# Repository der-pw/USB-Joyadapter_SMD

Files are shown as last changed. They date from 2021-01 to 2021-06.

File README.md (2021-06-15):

# USB-Joyadapter_SMD  
ATtiny basierter USB adapter für classic DB9 joysticks.

Die Ursprungsidee kommt aus dem forum64.de.  
https://www.forum64.de/index.php?thread/43055-usb-joystickadapter-neue-firmware-weiterentwicklung/

Die Software ist frei verfügbar und wird u.a. in dem [Thread](https://www.forum64.de/index.php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) zum Download angeboten, alle anderen Quellen, zumindest die, die ich gefunden habe, laufen ins Leere.
Daher stelle ich die Daten, der Vollständigkeit halber in dem Ordner [USB-Joystickadapter_THT](https://github.com/der-pw/USB-Joyadapter_SMD/tree/main/USB-Joystickadapter_THT) mit zur Verfügung. Darin enthalten sind sowohl die Software, zwei kompillierte Versionen, einmal für ATtiny2313 und ATtiny4313 und zusätzlich auch die Boarddaten der "alten" THT-Version.  
Ich bin aber nicht der Author!

Ich wollte eine SMD Version, möglichst kompakt aber noch gut zum Handlöten, haben.
Das Platinenlayout liegt als [KiCad-Projekt](https://github.com/der-pw/USB-Joyadapter_SMD/tree/main/kicad) vor. Exportierte Gerberdaten für Fertiger (bspw. [JLCPCB](https://jlcpcb.com/)) kann man ebenfalls [hier herunterladen](https://github.com/der-pw/USB-Joyadapter_SMD/raw/main/Joyadapter_SMD_gerber.zip).

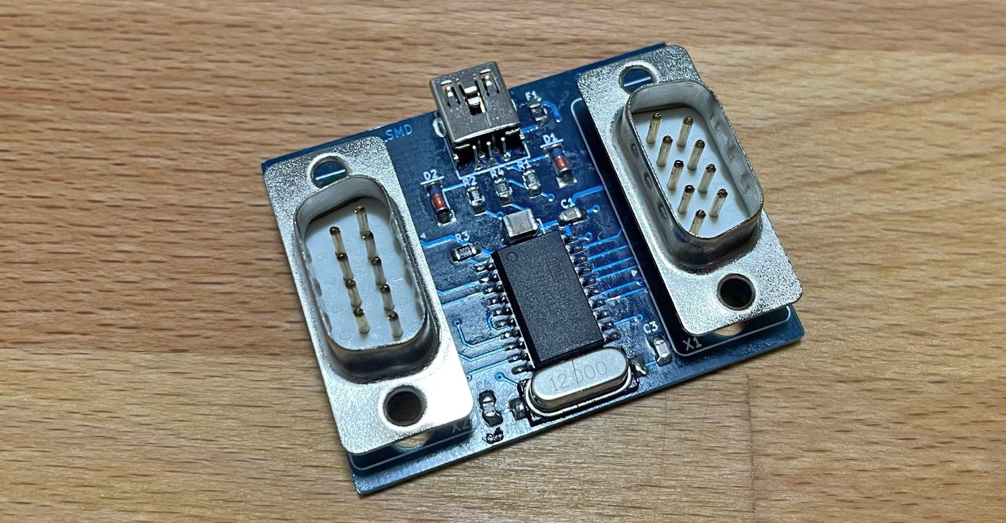
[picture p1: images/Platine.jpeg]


### Programmierung
Ich habe das Hexfile mittels [AVRDUDESS](https://github.com/zkemble/AVRDUDESS) und einem ISP-Programmer auf den ATtiny geschrieben.
Die ISP-Schnittstelle wurde aus Platzgründen als SMD-Pads ausgeführt.
Eine Möglichkeit, man lötet Verbindungskabel zum Programmer an, ober man baut mit einer Buchsenleiste 6x1 RM2,54, 6 Pogo-Pins (P50-B1) und dem [Adapter](https://github.com/der-pw/USB-Joyadapter_SMD/blob/main/3D%20print/Pogo-Adapter.stl) eine Programmierklemme.
Da man das Teil prinzipiell nur einmal flashed und die Software ist m.E. ausentwickelt, kann man wohl eher kurz ein paar Kabel anlöten.

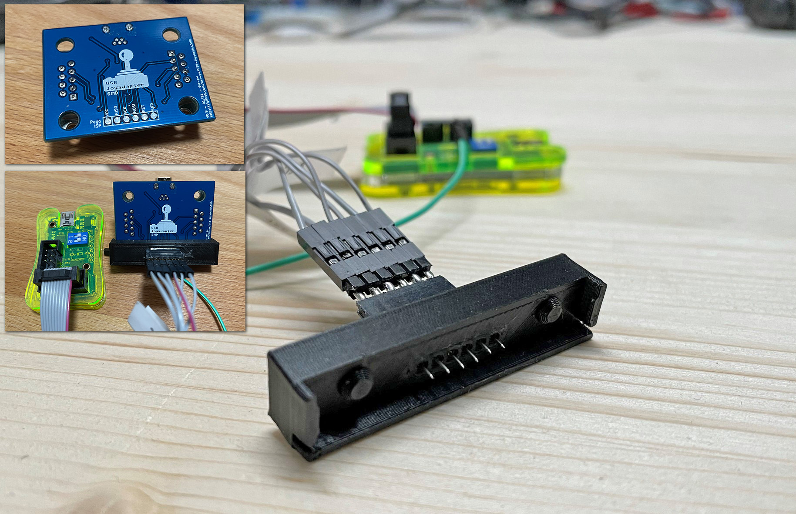
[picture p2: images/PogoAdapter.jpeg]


Die Fuses habe ich folgendermaßen gesetzt.  
**Low:** *0xCF*  
**High:** *0xDB*  
**Ext:** *0xFF*  
Fusecalc: https://www.engbedded.com/fusecalc/

### Gehäuse
Es gibt auch ein Gehäuse in der Variante mit den hochstehenden DB9-Buchsen.  
Zum Festschrauben beider Gehäusehälften wurden 2x12mm Linsenkopfschrauben verwendet.

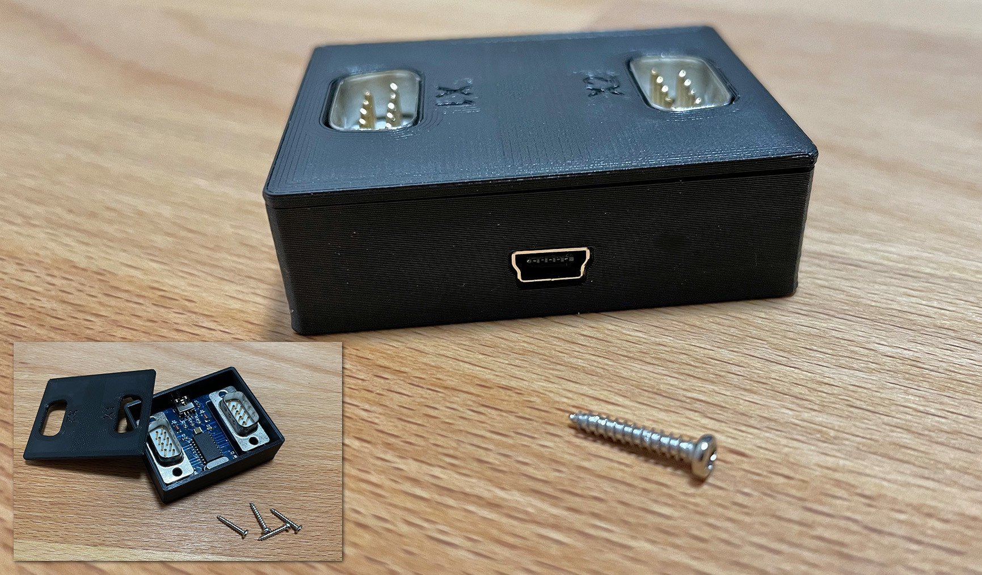
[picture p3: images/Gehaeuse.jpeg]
Gehäuse


Alternativ könnte man auch 90° gewinkelte DB9-Buchsen verwenden. Dann gucken die Kabel rechts und links aus dem Gehäuse heraus.
Ich wollte es erst einmal recht kompakt haben.
Vielleicht ergibt sich nochmal die Gelegenheit für ein Gehäuse mit 90° Buchsen.

### Teileliste:
https://www.reichelt.de/my/1803950  
Einige Teile sind (Stand 06.21) schwer zu bekommen.  

Ein großer **Dank** geht an das [forum64.de](https://www.forum64.de/) und seine hilfsbereiten Mitglieder. :thumbsup:

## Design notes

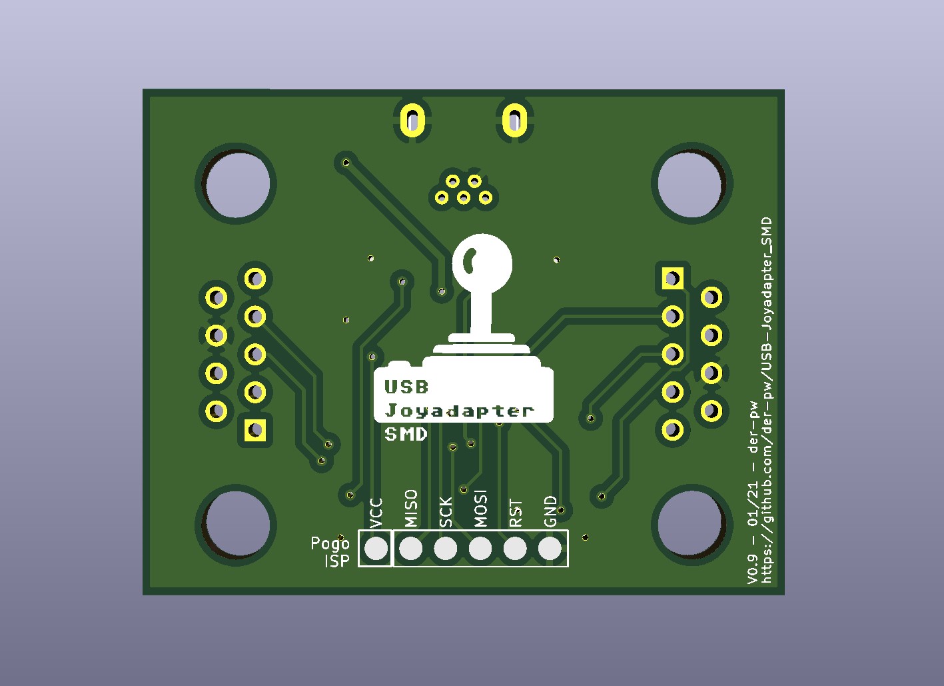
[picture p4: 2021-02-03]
images/3D_bottom_side.jpg

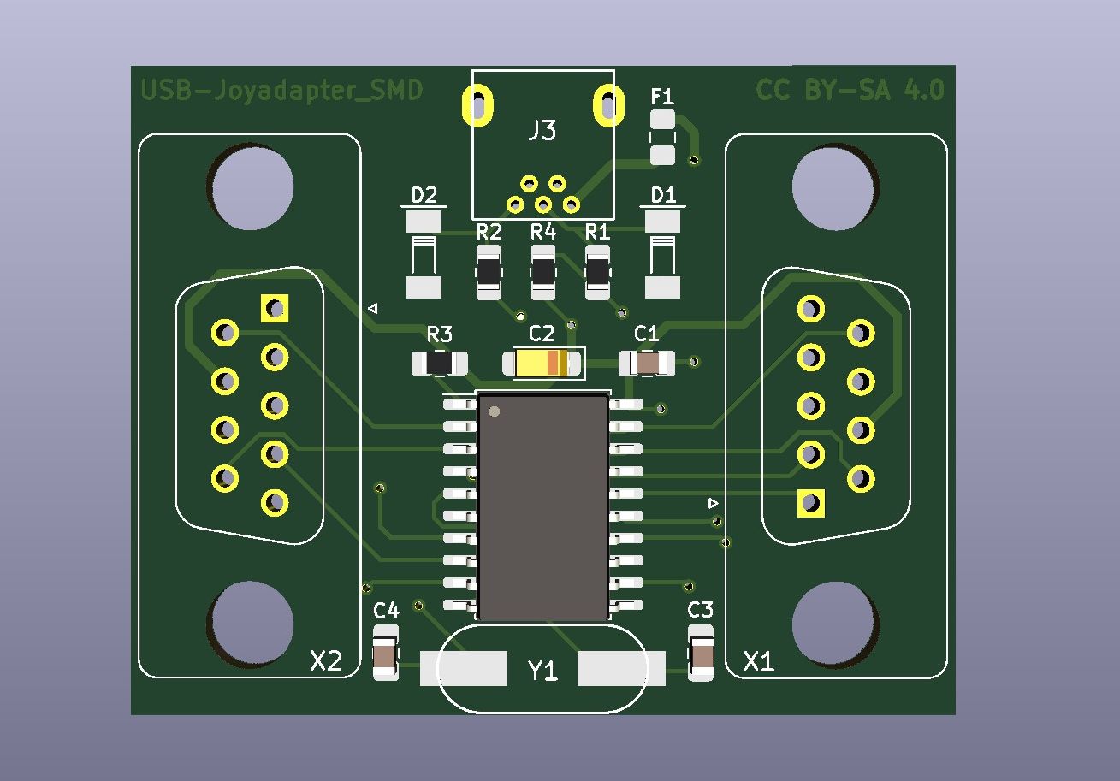
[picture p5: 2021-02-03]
images/3D_top_side.jpg

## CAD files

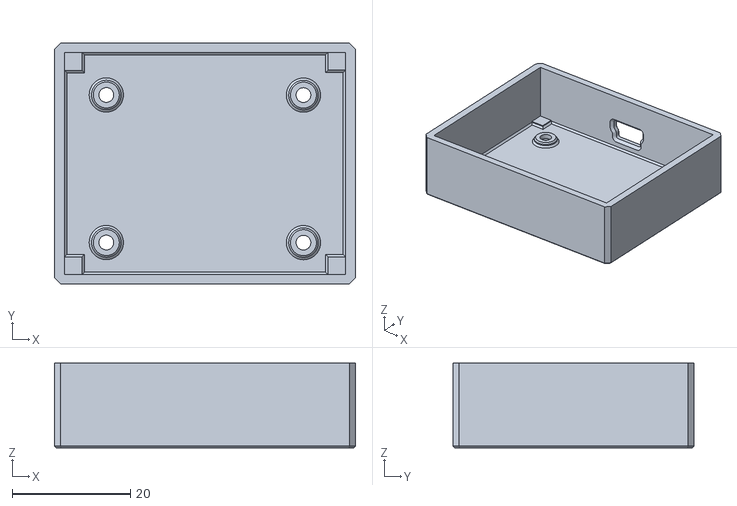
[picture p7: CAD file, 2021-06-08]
3D print/Case_bottom.stl
51.0 x 40.8 x 14.4

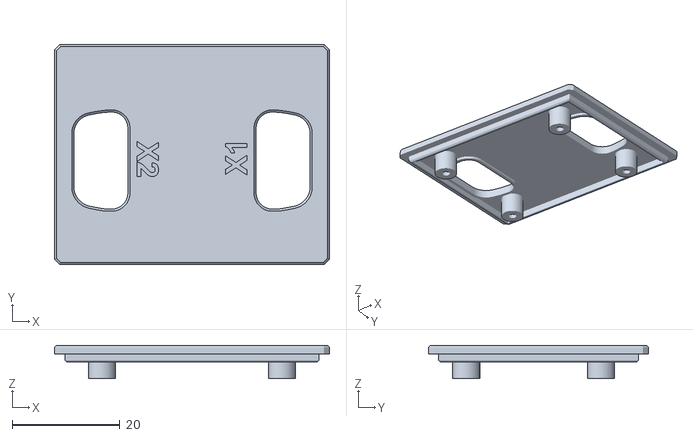
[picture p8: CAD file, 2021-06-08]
3D print/Case_top.stl
51.0 x 40.8 x 6.20

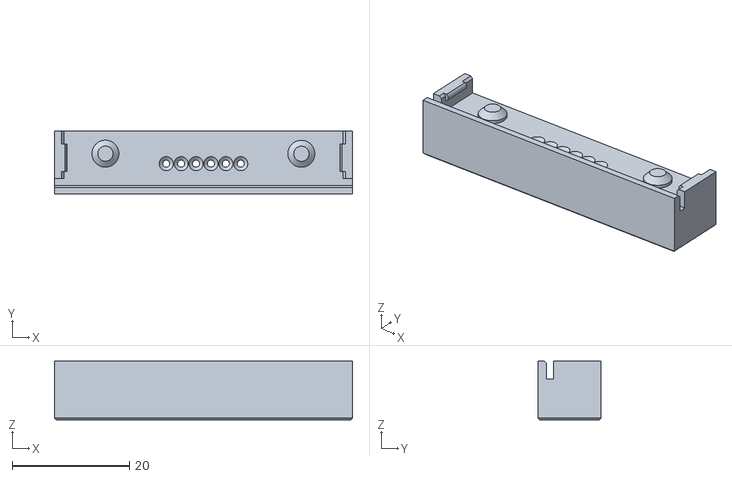
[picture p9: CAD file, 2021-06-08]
3D print/Pogo-Adapter.stl
50.8 x 10.8 x 10.0

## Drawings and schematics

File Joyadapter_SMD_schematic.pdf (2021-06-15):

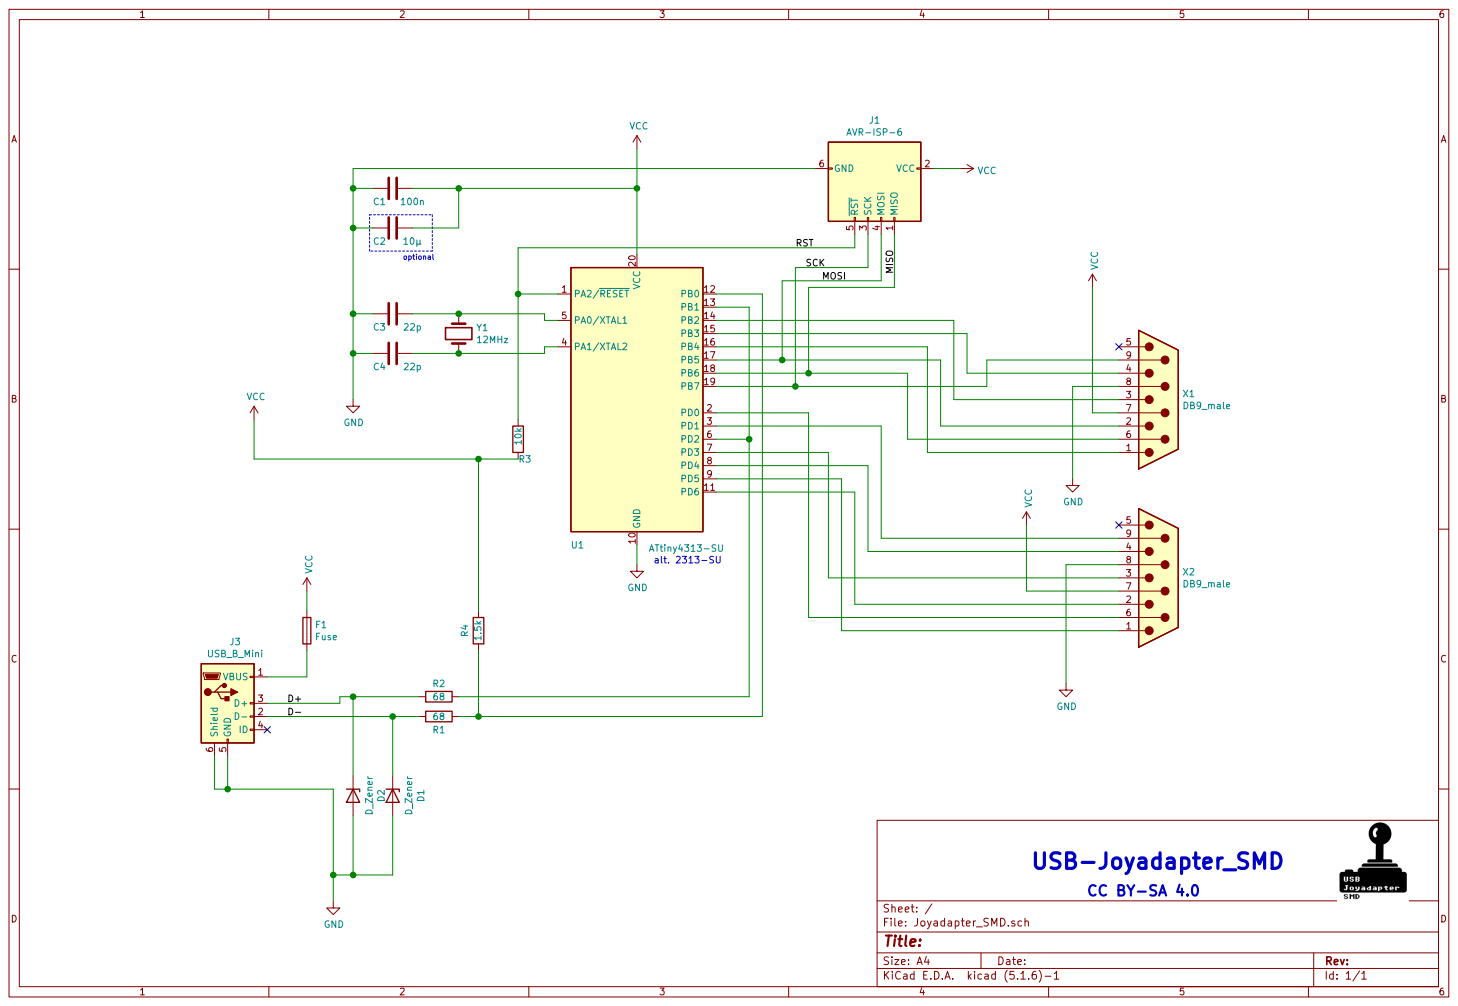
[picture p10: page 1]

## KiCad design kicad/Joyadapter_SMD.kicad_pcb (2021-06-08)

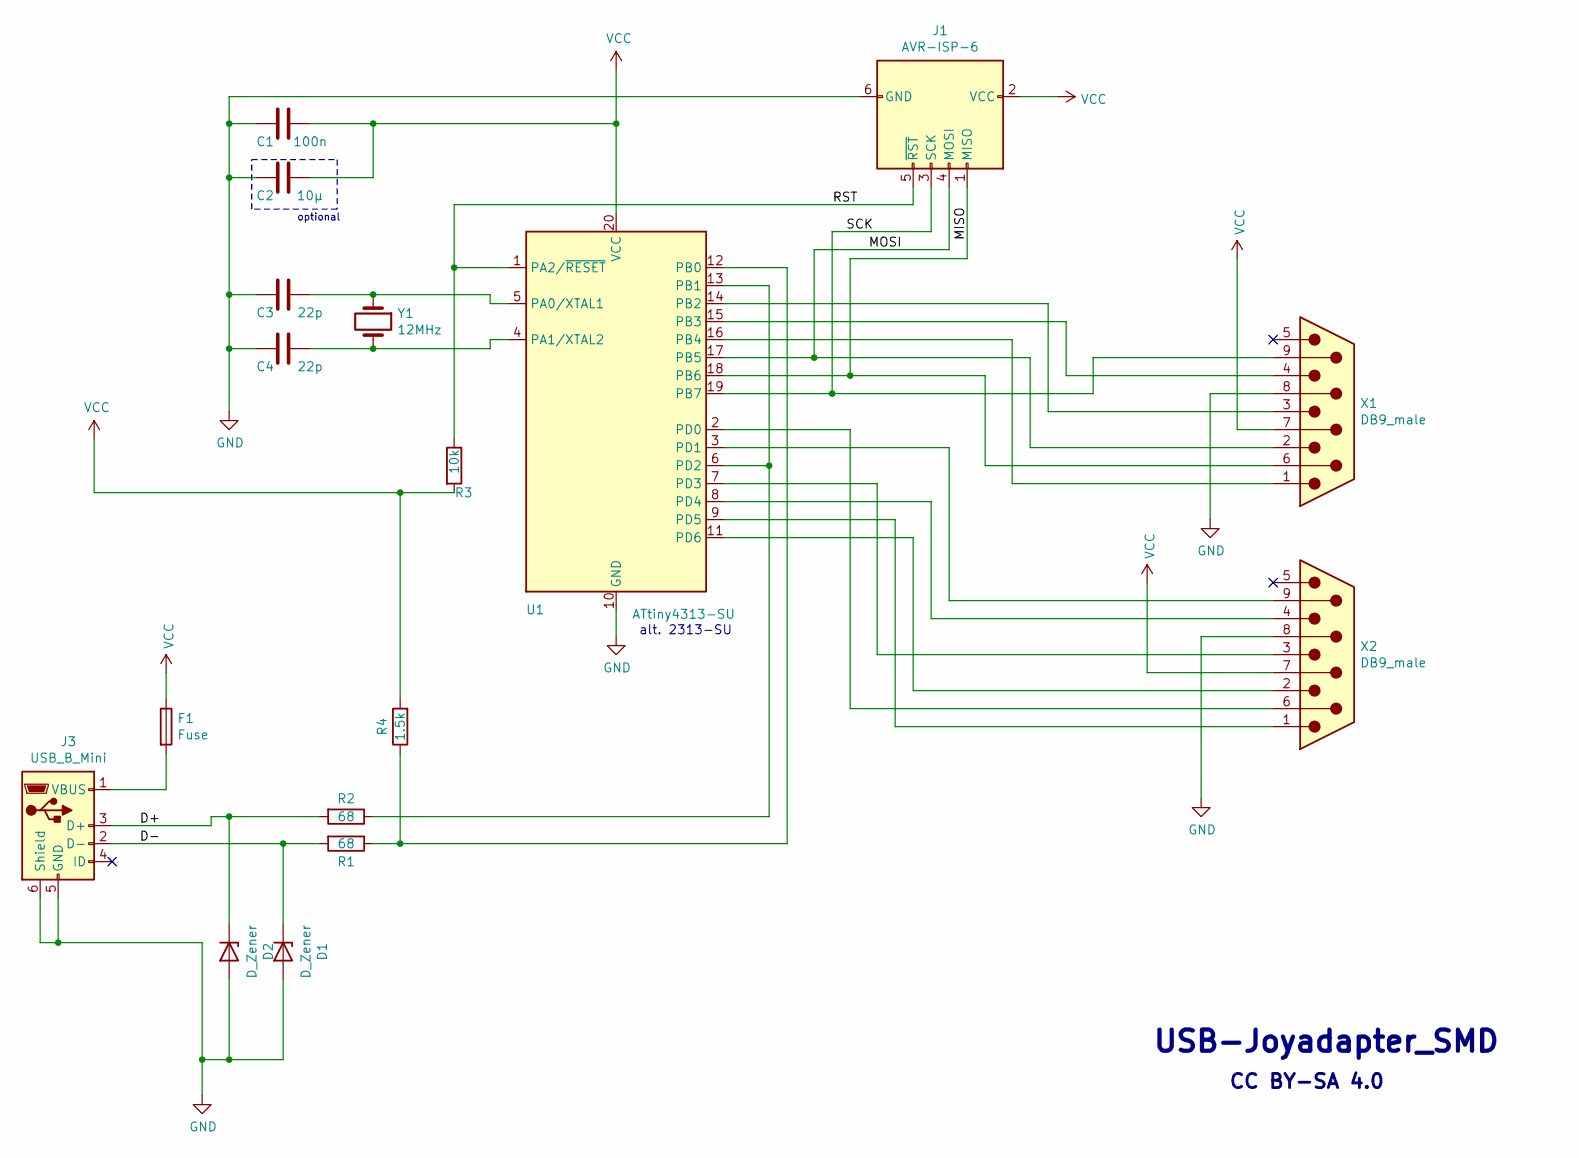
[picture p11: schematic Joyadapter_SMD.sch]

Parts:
C1: 100n; C_0805_2012Metric_Pad1.18x1.45mm_HandSolder
C2: 10µ; CP_EIA-3216-18_Kemet-A_Pad1.58x1.35mm_HandSolder
C3, C4: 22p; C_0805_2012Metric_Pad1.18x1.45mm_HandSolder
D1, D2: D_Zener; SOD-80
F1: Fuse; Fuse_0805_2012Metric_Pad1.15x1.40mm_HandSolder
J1: AVR-ISP-6; PinHeader_1x06_P2.54mm_Vertical
J3: USB_B_Mini; USB BWM USB-Einbaubuchse B-Mini
R1, R2: 68; R_0805_2012Metric_Pad1.20x1.40mm_HandSolder
R3: 10k; R_0805_2012Metric_Pad1.20x1.40mm_HandSolder
R4: 1.5k; R_0805_2012Metric_Pad1.20x1.40mm_HandSolder
U1: ATtiny4313-SU; SOIC-20W_7.5x12.8mm_P1.27mm
X1, X2: DB9_male; DSUB-9_Male_Vertical_P2.77x2.84mm_MountingHoles
Y1: 12MHz; HC49-SMD

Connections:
/D+: D2.1 (K), J3.3 (D+), R2.2
/D-: D1.1 (K), J3.2 (D-), R1.2
/MISO: J1.1 (MISO), U1.18 (PB6), X1.6
/MOSI: J1.4 (MOSI), U1.17 (PB5), X1.2
/RST: J1.5 (~RST), R3.1, U1.1 (PA2/~RESET)
/SCK: J1.3 (SCK), U1.19 (PB7), X1.9
GND: C1.2, C2.2, C3.2, C4.2, D1.2 (A), D2.2 (A), J1.6 (GND), J3.5 (GND), J3.6 (Shield), U1.10 (GND), X1.8, X2.8
unnamed: C3.1, U1.5 (PA0/XTAL1), Y1.1
unnamed: C4.1, U1.4 (PA1/XTAL2), Y1.2
unnamed: F1.2, J3.1 (VBUS)
unnamed: R1.1, R4.1, U1.12 (PB0)
unnamed: R2.1, U1.6 (PD2), U1.13 (PB1)
unnamed: U1.2 (PD0), X2.6
unnamed: U1.3 (PD1), X2.9
unnamed: U1.7 (PD3), X2.3
unnamed: U1.8 (PD4), X2.4
unnamed: U1.9 (PD5), X2.1
unnamed: U1.11 (PD6), X2.2
unnamed: U1.14 (PB2), X1.3
unnamed: U1.15 (PB3), X1.4
unnamed: U1.16 (PB4), X1.1
VCC: C1.1, C2.1, F1.1, J1.2 (VCC), R3.2, R4.2, U1.20 (VCC), X1.7, X2.7

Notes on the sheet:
alt. 2313-SU
optional
USB-Joyadapter_SMD
CC BY-SA 4.0

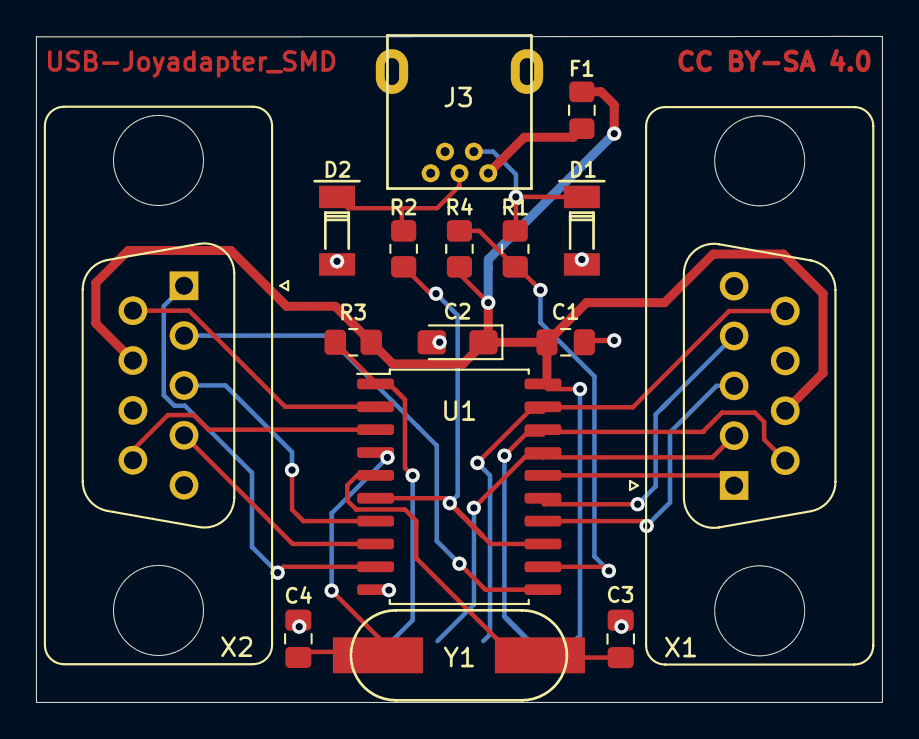
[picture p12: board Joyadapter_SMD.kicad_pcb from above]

Board: 2 copper layers, 47.0 x 37.0 mm, 17 parts (1 on the bottom side), 22 nets.

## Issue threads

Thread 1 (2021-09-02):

BOM for SMD Version

homekiciarz, 2021-09-02:
Hello. I try to make this project.
I Can't find anywhere BOM for this project so i decide to try made one myself.
Can You confirm or correct it and add to Your project for other people.

U1 ATtiny4313-SU/ATtiny2313-SU
D1,D2 Zener Diode (I don't know what parameters they are have)
F1 0805 Fuse
R1,R2 0805 Resistor 68R
R3 0805 Resistor 10k
R4 0805 Resistor 1,5k
C2 3216 Tantal Capacitor 10uF
C1 0805 Capacitor 100nF
C3,C4 0805 Capacitor 22pF
Y1 Crystal 12MHz SMD

Please insert correct values for D1 and  D2

der-pw, 2021-09-02:
Hi,
I just created the parts list at Reichelt.
I didn't do a BOM yet. I probably forgot to add the zener diodes, sorry. It is a "SMD ZF 3.6 Zener diode, 3.6 V, 0.5 W, SOD80".
I have now also added it to my Reichelt list. Incidentally, I had not solder the fuse, but rather short-circuited the pads.
Otherwise, your list looks fine.
You can leave out C2. I made the pad just to be on the safe, in critical cases. I try to leave out tantalum as much as possible.
The Attiny runs fine, just with the 100nF.

Closed 2021-09-04.

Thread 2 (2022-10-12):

Compatibility with TheA500 mini.

homekiciarz, 2022-10-12:
Hello. Is there posibility to use that adapter with The A500 mini ? What firmware i need to put inside ?

der-pw, 2022-10-12:
The original game controller is connected to the A500 mini via USB, so I think it's possible, but I'm not absolutely sure.

The FIrmware was part of the original adpater under forum64.de, here You'll find it.
https://www.forum64.de/index.php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
There was no license, and I didn't want to share it here in my repo.

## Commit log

2021-01-21 upload kicad Data
    [Joyadapter_SMD.kicad_pcb, Joyadapter_SMD.sch]
2021-02-03 Update
    Fuse added
    [Joyadapter_SMD.kicad_pcb, Joyadapter_SMD.sch]
2021-06-08 Update PCB to V1.0
    [Case_bottom.stl, Case_top.stl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]
2021-06-15 add schematic

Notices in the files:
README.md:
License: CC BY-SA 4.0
